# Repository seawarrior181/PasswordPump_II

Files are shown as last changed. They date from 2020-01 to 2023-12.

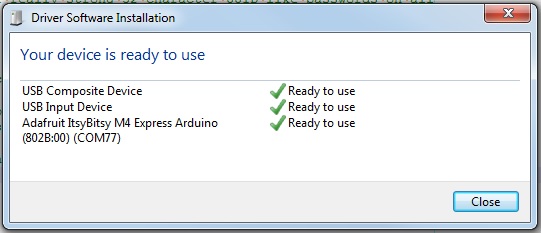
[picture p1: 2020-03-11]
media/DeviceDriversInstalled.jpg

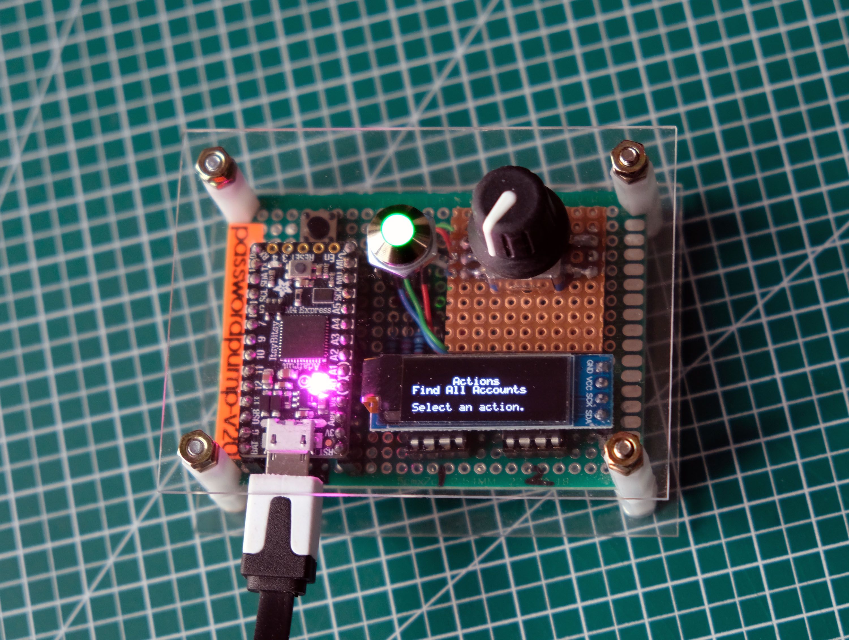
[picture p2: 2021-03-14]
media/NewDesignByCustomer.jpeg

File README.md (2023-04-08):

# PasswordPump v2.0

This is v2.0 of the PasswordPump, a USB device that manages credentials for up to 250 accounts.  Credentials (account names, usernames, passwords, URLs and old passwords) are stored ONLY on the device itself, on two removable EEprom chips using military grade encryption (AES-256).  The credentials are not stored in the cloud or in a file on your computer where they are more exposed to hackers.  Credentials are backed up on the device itself; i.e. encrypted credentials are moved from the primary EEprom chip to the backup EEprom on demand.  You may remove the EEprom chips from the device (perhaps to keep a third or fourth backup).  Credentials are entered either via the rotary encoder (on the left), via keyboard and serial terminal, or via a Python based graphical user interface (the PasswordPumpGUI).   The device itself is approximately 1 1/8 x 2 3/4 inches, or 29 x 71 millimeters.  Cases are available for printing.  If you design another case for the PasswordPump please share it with us!

The purpose of this repository on GitHub is to disseminate software for and information about the PasswordPump v2.0.  See the Password Pump II Users Guide.pdf and https://5volts.org for details.  

If you are simply wanting to download the latest version of the PasswordPump software onto your PasswordPump device follow the instructions provided in the "Burning Firmware From the BOSSA GUI" section of the Users Guide.

It is always wise to download the latest version of the PasswordPumpGUI when you are downloading the latest version of PasswordPump_v_2_0.ino.

If you are interested in printing the case (at https://github.com/seawarrior181/PasswordPump_II/blob/master/3D-Print), take a look here https://github.com/seawarrior181/PasswordPump_II/tree/master/media for pictures and instructions related to how the case can be further modified.  Thanks to Kevin Lever for these suggestions.

Note about v2.0.5 of the PasswordPump:
If I shipped to you a PasswordPump which indicates that it is at v2.0.5, it will most likely have a "lefty" encoder.  This means that as you turn the rotary encoder clockwise, it proceeds backwards through the alphabet instead of forwards.  Some folks find this counter intuitive.  To fix this you merely need to navigate to Settings->Encoder Type and change it from ‘Normal’ to ‘Lefty’; and don’t worry, the setting is remembered if you power cycle the device.  If you factory reset the device you’ll need to change the Encoder Type to Lefty again.

# News
  * The .stl files for the Joystick Model case have been posted, thanks to Scootercommuter.
  * A new release of the firmware is available, Version:2.0.8.02, which addresses an issue with the handling of group names between the PasswordPump and the PasswordPumpGUI.
  * There is now a new model of PasswordPump available for purchase; the Joystick model.  This PasswordPump has a lower profile, but it does take a little bit longer to scroll through all of your accounts.  It works well.
  * On Windows there exists now a setup program that does not require Python to be installed to get the PasswordPumpGUI up and running.  Click on it's location to download:
      https://github.com/seawarrior181/PasswordPump_II/raw/master/v2_0_8/PassPumpGUI/inno/PasswordPumpSetup.exe
    
    Simply execute the downloaded file to get the PasswordPumpGUI installed.
      
  * There are several new cases to announce; there is a new case for the rotary encoder model available on Tindie.  Soon to follow there will be a new case available for the Joystick model that looks pretty cool.  Both of these cases were designed and donated by scootercommuter.  Because 3D printing is expensive I'll be selling them on Tindie for a price that's quite close to my cost.  Finally there is an acrylic enclosure on the way, the enclosure that's depicted on the front of the Users Guide.  The .stl files for the two cases are posted on this site so that you can print them out yourself if you have a 3D printer (thanks scootercommuter!).  Finally, if you are interested in any of these cases/enclosures and they are not in stock on Tindie send me an email so that I know there is interest.  There are pictures of all three designs in the media section of this site, located here (best viewed by downloading):

      https://github.com/seawarrior181/PasswordPump_II/blob/master/media/PPEncoder.jpg
      https://github.com/seawarrior181/PasswordPump_II/blob/master/media/PPEncoderEnclosure.jpg
      https://github.com/seawarrior181/PasswordPump_II/blob/master/media/PPEncoderCase.jpg
      https://github.com/seawarrior181/PasswordPump_II/blob/master/media/PPJoystick.jpg
      https://github.com/seawarrior181/PasswordPump_II/blob/master/media/PPJoystickCase.jpg
  
# Change Log

v2.0.8 2023-04-08
  * Added a feature whereby if your Settings-->Timeout Minutes is set to Never, your screen goes dark after 5 minutes of inactivity.  Then you may actuate the rotary encoder in any way (which is automatically interpreted as a long click) to turn the display back on.  The purpose of this feature is to prevent the screen from burning in, a problem I've noticed after long-term use of the PasswordPump.

v2.0.8
  * When you backup to PasswordPump format from PasswordPumpGUI any custom group/category names are now saved.
  * A defect that was preventing the import of Chrome formatted export files is addressed.
  * Fixed an issue with the handling of group names between the PasswordPump and the PasswordPumpGUI.
  * Created an install/setup program for the PasswordPumpGUI using Inno.
  * Modified the PCB design to accomodate a joystick instead of a rotary encoder.
  * Added compile time directives to compile for rotaray encoder or joystick model.
  * Added the ability to download the latest version of the PasswordPumpGUI to the PasswordPumpGUI.
  * Added the ability to download the latest versions of the firmware from the PasswordPumpGUI.

2020-12-31 v2.0.6
  * Made some minor edits to the PasswordPumpGUI menus
  * Accepted design docs for an exceptionally well done case, here: https://github.com/seawarrior181/PasswordPump_II/tree/master/3D-Print/scootercommuter_Design
  * Added a setting that allows for the introduction of delay between the transmission of each character to the compuer/tablet/phone so that slower devices do not drop characters. 
  * Added the ability to set the default length of the generated password; 8, 10, 16, 24, or 31.
  * Fixed a problem with saving PasswordPump export files on Linux.
  * Added encryption and decryption of PasswordPump export files produced in PasswordPumpGUI.
  * Added a dialog box used on exit to confirm exit from PasswordPumpGUI.
  * Fixed an issue with style default value sometimes not getting handled correctly in PasswordPumpGUI.
  * Enforced a rule that device generated passwords must pass the same compexity check as the PasswordPumpGUI generated passwords.
  * Added the ability to edit RGB LED intensity, login attempts before logout, and  minutes before automatic logout from the PasswordPumpGUI.
  * Changed the behavior of sending a password so that a <TAB> character is sent before the <CR> carriage return character is sent.  This helps with automatically logging all the way into certain sites.
  * Added a feature whereby after 1 minute of inactivity the time remaining before automatic logout is displayed on the device.
  * Fixed a defect in PasswordPumpGUI whereby you could navigate to and edit fields before the port was open, resulting in the display of error messages.
  * Cleaned up Factory Reset to reset more values, like keyboard language, encoder type, logout timeout, so that they would not persist after a soft reset (a reset performed by selecting Factory Reset from the menu).  The values were not persisting after a hard reset.
  * Fixed a defect in Fix Corruption whereby if the head of the linked list was deleted, Fix Corruption would effectivly wipe out the ability to navigate to all accounts.
  * Updated the version number from v2.0.5 to v2.0.6.

2020-10-17 v2.0.5

  * Added the fix corrupt account list feature to the PasswordPumpGUI_v2_0.py.
  * A customer has recently reported to me that the linked list that keeps the credentials sorted by account name is becoming corrupt, which is affecting his ability to navigate through the credentials on the device via the rotary encoder or via the PasswordPumpGUI.  Toward fixing that problem I have added a menu option entitled Fix Corruption.  It is not clear to me yet how this corruption is introduced, as I am unable to reproduce the conditions under which the defect occurs in my lab.
  * Added a feature in settings whereby you can remap the orientation of the PasswordPump's text so that you can use it with the rotary encoder on the left (default) or the right.
  * Added the ability in settings to select from a variety of fonts for the PasswordPump's display.
  * Fixed several issues with menu navigation; selecting 'N' and not being returned to the top of the main menu, long clicking and the screen not clearing.
  * Removed the font fixednums8x16 which wasn't working, resulting in losing all creds.
  * Changed the default font.
  * Added a feature whereby the user can select from a variety of different fonts.

2020-07-24 v2.0.4 
  * Made the encoder type configurable; i.e. to handle 'lefty' encoders w/o the precompiler directive.
  * Fixed a problem with the way PasswordPumpGUI handled style when it's set to 255 (the default before it's written to EEprom).
  * Added support for Czech, Danish, Swedish, Norwegian, Finnish, French, German and Spanish keyboards.  US is the default.  See the Known Defects section of the Users Guide for more information about this functionality.
  * Fixed a problem with navigating back to the correct main menu elements on long click.
  * Fixed the Style dropdown in PasswordPumpGUI to show the inter username / password character's name instead of the value stored behind the scenes.
  * Added a check in PasswordPumpGUI for password complexity.  Informational only.
  * In the PasswordPumpGUI, added the ability to check to see if your password has ever been discovered in a known data breach (pwned).
  * Added the ability to customize the group names via PasswordPumpGUI.  
  * Added Factory Reset to the PassPumpGUI program. 
  * Added a pre-compiler directive to deal with "lefty" rotary encoders; see users guide for more info.  (Obsolete). 
  * Modified the custom PCB and added a pre-compiler directive for use with Adafruit ItsyBitsy M0. 
  * Fixed the defect whereby entering the decoy password did not result in a factory reset. 
  * Tweaked the mechanism for generating a random seed.  
  * Fixed the following defect: Via PasswordPumpGUI Insert, then (Alt)(Tab) to navigate to another application;  Upon returning to PasswordPumpGUI the Account Name is "Unknown";  Set focus to another account, the PasswordPump and PasswordPumpGUI freeze;  Close the PasswordPumpGUI window and long click on the PasswordPump;  Now there is only one account in the PasswordPump; Restore from secondary EEprom.  This issue is resolved.

2020-04-26 v2.0.3 
  * Fixed a defect discovered by Neil whereby the @ needed to be added back to the list of characters available for input via rotary encoder.  
  * Fixed an error whereby you could scroll past the z when entering characters via rotary encoder.  
  * Changed automatic logout from the device so that it does not automatically lock your computer. 
  * Fixed a defect whereby when long clicking after search by group you didn't return to the right group you always returned to favorites.  
  * Changed the Credentials menu so that you always know which account you're in.  
  * Fixed a problem in the Settings menu where you were not returning to the menu item from which you came.  
  * Fixed some issues with menu navigation when long clicking to make it more intuitive.  
  * Added the ability to customize the names of groups.  
  * Fixed a defect in PasswordPumpGUI whereby the value of a text box where the cursor is positioned before the Insert menu item is selected becomes blank after a new record is inserted by eliminating Insert (and Delete) from the File menu and substituting buttons for those functions. 
  * Fixed an issue discovered by Neil whereby the custom group names were not reflected in PasswordPumpGUI.

2020-02-24 v2.0.2 Eliminated the need for the PyCmdMessenger edits.  You still need to install PyCmdMessenger, you just don't need to make any edits to it.

2020-02-22 v2.0.1 Fixed an issue whereby the 124th account was not handled correctly under a variety of different situations.  Changed PassPumpGUI_v2_0_0.py and PasswordPump_v_2_0_0.ino.

2020-02-17 v2.0.0  Versioned all of the programs and documention, set them to v2.0.0.  There were minor cosmetic changes to the software related to the new version number.  PasswordPumpGUI was modified to size the main window based on the operating system.

2020-02-15 no rev  Added a feature whereby when you select logout from the main menu on the PasswordPump, you're logged out of the PasswordPump and the computer screen is also locked.  Changes the behavior of the splash screen; no more scrolling PasswordPump and a faster startup.

# Video

https://youtu.be/f4Iukt5VDUo

# License

<br />This work is licensed under a <a rel="license" href="http://creativecommons.org/licenses/by-nc-sa/3.0/">Creative Commons Attribution-NonCommercial-ShareAlike 3.0 Unported License</a>.

This program and device are distributed in the hope that they will be 
useful, but WITHOUT ANY WARRANTY; without even the implied warranty 
of MERCHANTABILITY or FITNESS FOR A PARTICULAR PURPOSE.

(c) 2020 Daniel Murphy

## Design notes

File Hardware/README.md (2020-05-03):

  
Note that the board in the DIPTrace PCB design is actually an ATMega32U4, not an ItsyBitsy M4, so the pad names are wrong.
This does not affect the design of the PCB.

I’m using DIPTrace to do the PCB design.  It’s freely available at https://diptrace.com/.  Download the DIPTrace file and open it with DIPTrace to edit the PCB design.  This is really the first PCB I’ve ever designed, so if you have suggestions please feel free to let me know.  I’ve also included the design files you’ll need if you want to order the custom PCB on your own.

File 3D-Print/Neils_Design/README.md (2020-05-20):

This case design is donated by my friend and beta tester Neil.  The design works best with this high quality magnetic USB cable: https://www.amazon.co.uk/NetDot-Generation-Magnetic-Smartphones-i-Product/dp/B07QKNF8Y7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

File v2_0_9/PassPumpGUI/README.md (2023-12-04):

# The PasswordPump Graphical User Interface

A project that exists to install the PasswordPumpGUI, [the Users Guide for which is found here][Users Guide].  Reading the users guide is stongly recommended before making a decision to acquire a PasswordPump.

[The source for this project is available here][src].

----

This is the README file for the project.

The PasswordPump is a USB device that manages credentials for up to 250 accounts.  Credentials (account names, usernames, passwords, URLs and old passwords) are stored ONLY on the device itself, on two removable EEprom chips using military grade encryption (AES-256).  The credentials are not stored in the cloud or in a file on your computer where they are more exposed to hackers.  Credentials are backed up on the device itself; i.e. encrypted credentials are moved from the primary EEprom chip to the backup EEprom on demand.  You may remove the EEprom chips from the device (perhaps to keep a third or fourth backup).  Credentials are entered either via the rotary encoder (on the left), via keyboard and serial terminal, or via a Python based graphical user interface (the PasswordPumpGUI).   The PasswordPump works with Windows, Mac OS, Linux distributions and Android (phones and tablets).  The device itself is approximately 1 1/8 x 2 3/4 inches, or 29 x 71 millimeters.

Features
- Stores up to 250 sets of credentials.
- Authenticates with a 15 character master password.
- Search for accounts.
- Data entry via rotary encoder or keyboard and serial monitor, or via client Python GUI running in Windows, Ubuntu, or MacOS.
- Sends a username and password to a computer as if typed in via the keyboard. Can also send URL, old password and account name.
- Add account name, username, password (generated or not), URL, old password
- Accounts are added in alphabetical order.
- Delete an account.
- Edit existing username, password, URL, style (inter-username/password characters, username<Return>password<Return>, username<Tab>password<Return> or username<Tab>password<Tab><Return>), old password, credential groups.
- Generate 8, 10, 16, 24, or 31 character random passwords from the PasswordPump or via the client GUI.
- Automatically saves the old password if it’s not already populated when you generate a password.
- Backup all accounts to a second encrypted external EEprom.
- Logout / de-authenticate via the menu, automatically locks the computer (Windows only).
- Configurable password display on or off.
- Configurable failed login count factory reset (3, 5, 10 or 25).
- Configurable automatic logout after count of minutes (30, 60, 90, 120, 240, 1 or Never).
- Configurable RGB LED intensity (high, medium, low or off).
- Configurable font.
- Configurable orientation, so that the encoder is on the left or the right.
- Configurable generated password size; 8, 10, 16, 24, 31.
- All account names, usernames, passwords and URLs are encrypted w/ AES-256.
- Master password is hashed w/ SHA-256.
- All encrypted credentials fields and the hashed master password are salted.
- The device is not vulnerable to standard password attacks.  See disclaimers.
- The master password can be changed.
- Export to PasswordPump formatted CSV file.
- Import from PasswordPump formatted CSV file.
- Import credentials from Chrome export.
- Import credentials from KeePass export.
- Associate credentials with custom groups for better organization; search by group (defaults are Favorites, Work, Personal, Home, School, Financial, Mail or Health).
- Decoy password feature that automatically factory resets the device if entered (e.g. while the user is under duress).
- Pre-auto-logout indicator/countdown via red and blue flashing RGB LED.
- Factory reset via menu (when authenticated) wipes out all credentials.
- Check if any password has been recovered in a data breach (pwned) on demand.
- Preliminary support for Czech, Danish, Swedish, Norwegian, Finnish, French, German, Spanish, United Kingdom and United States keyboards.
- Displays time left until automatic logout from the device occurs.
- Allows for setting Inter Character Delay for compatibility with some phones and tablets.

[Users Guide]: https://github.com/seawarrior181/PasswordPump_II/blob/master/Password%20Pump%20II%20Users%20Guide.pdf
[src]: https://github.com/seawarrior181/PasswordPump_II

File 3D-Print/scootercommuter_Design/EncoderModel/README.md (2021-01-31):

Here's are some cases made by scootercommuter in OpenSCAD.  All dimensions are calculated in OpenSCAD from the assembled board dimensions (by his caliper measurements). 

With respect to the Rotary Encoder case:
* The cover can be put on, and removed, without removing the knob (easier on the rotary encoder).
* It has rounded corners, which I personally prefer.
* The USB cable hole is made to fit the USB cable supplied by the PasswordPump Store.  The top is slotted for the cable also.  Probably most cables will fit.
* The fit of the knob hole is dependent on the positioning of the rotary encoder when it is soldered in.  So, he left a lot of slack with the hole size.
* Only 3 screws can be used due to the positioning of the RGB LED.
* It needs to be printed with supports enabled, because of the countersink holes and the oval USB hole.

It is designed for M2 x 8mm screws and hex nuts.  He had button hex head screws, but pan head will work just fine.  Scootercommuter had an issue with the "Hilitchi" brand screws he bought -- the "8mm" long screws are actually just 7.85mm long, so they barely were able to engage the hex nuts.  During his struggles with this, he opted for hexagonal countersink holes for obvious reasons.

The Joystic case is very similar to the encoder case, except it is designed to work well with the Joystick model of the PasswordPump.  It also has nubs that fit over the joystick for a professional finish.  

Print out a case on your 3D printer or order one from ThingVerse.  They cost about $12 to print in quantity (an order of 10 or more).

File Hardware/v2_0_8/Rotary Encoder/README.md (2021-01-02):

This version of the PasswordPump custom PCB (v2.0.7) will accomodate the Adafruit ItsyBitsy M0 or the Adafruit ItsyBitsy M4; with the RGB LED working correctly with either board.

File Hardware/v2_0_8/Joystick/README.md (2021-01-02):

This version of the PasswordPump custom PCB (v2.0.8) will accomodate the Adafruit ItsyBitsy M0 or the Adafruit ItsyBitsy M4; with the RGB LED working correctly with either board.

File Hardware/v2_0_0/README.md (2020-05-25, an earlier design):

This is the directory for v2_0_0 of the PasswordPump custom PCB.  It will accomodate the Adafruit ItsyBitsy M4 or the Adafruit ItsyBitsy M0; however, with the M0 the RGB LED will not always work correctly.

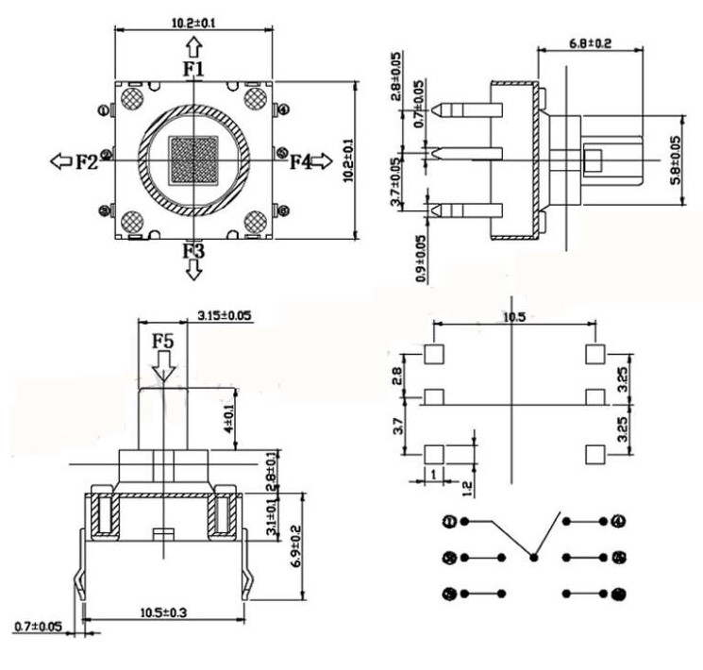
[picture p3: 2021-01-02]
media/JoystickPinout.jpg

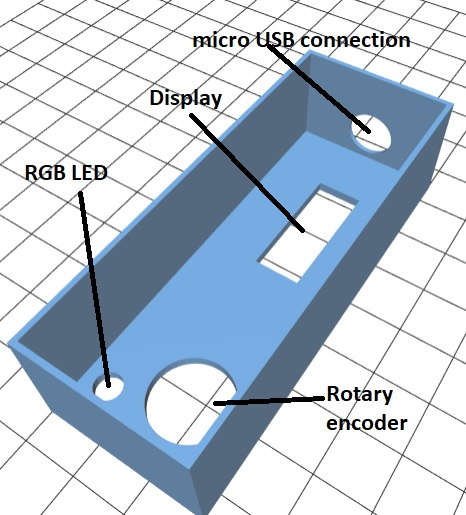
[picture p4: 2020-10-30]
media/CaseDesignInfoTop.jpg

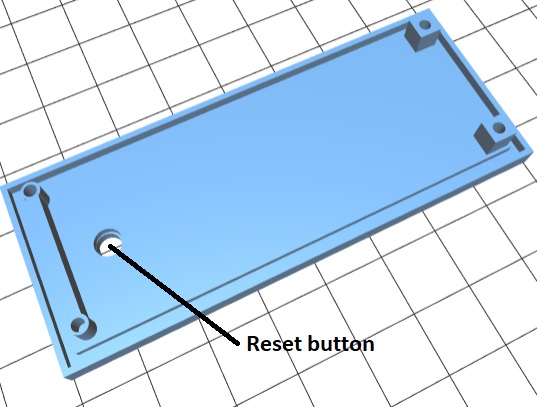
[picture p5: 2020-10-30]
media/CaseDesignInfoBottom.jpg

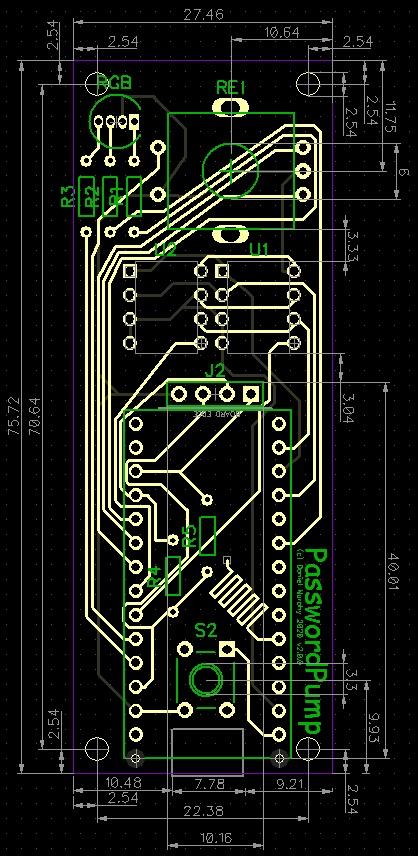
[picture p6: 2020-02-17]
Hardware/PasswordPumpDimensions.jpg

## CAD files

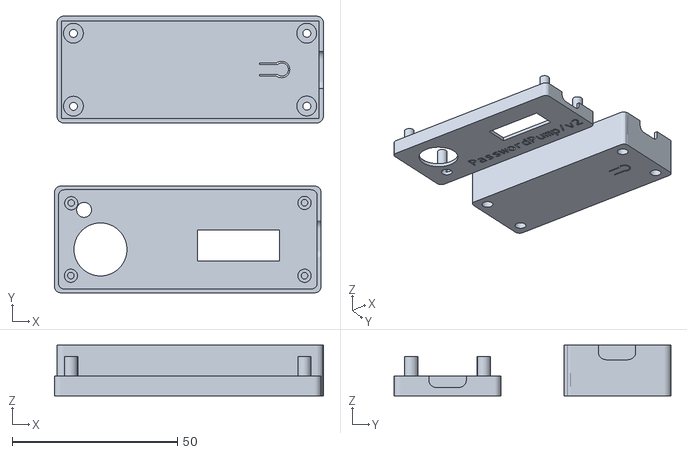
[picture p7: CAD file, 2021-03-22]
3D-Print/Jimmys_Design/PassPumpCase.stl
81.3 x 83.6 x 15.3

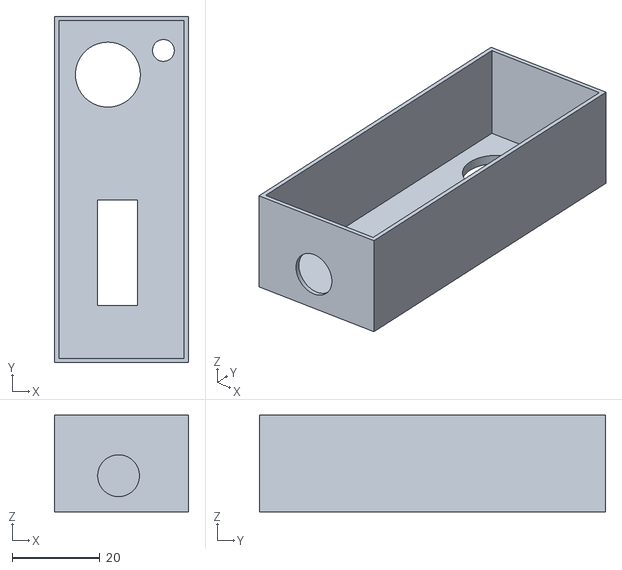
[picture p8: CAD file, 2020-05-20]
3D-Print/Neils_Design/passpump-v2-top.stl
30.5 x 78.7 x 21.9

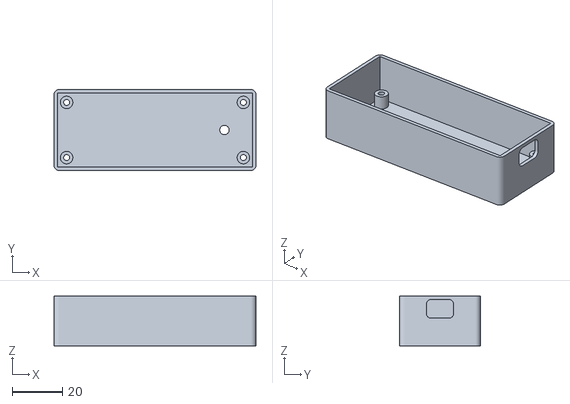
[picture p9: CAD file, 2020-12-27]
3D-Print/scootercommuter_Design/EncoderModel/EncoderPwdPumpBoxV2-kl6.stl
80.5 x 32.2 x 19.8

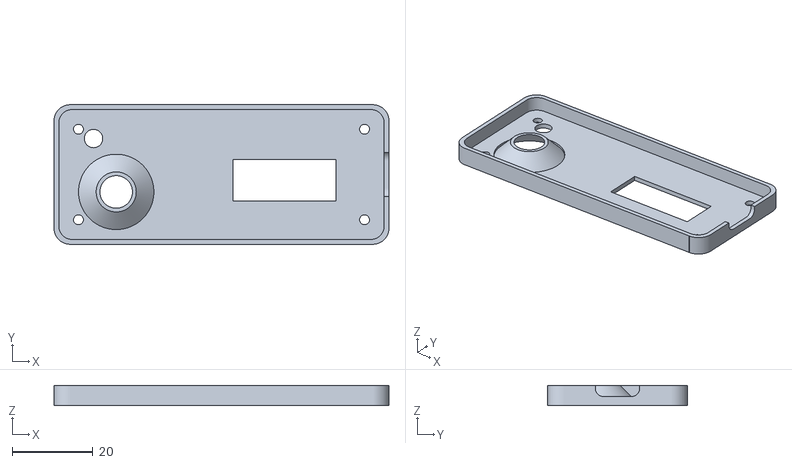
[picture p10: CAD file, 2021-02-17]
3D-Print/scootercommuter_Design/JoystickModel/PwdPumpV2_Joystick-Lid.stl
82.7 x 34.5 x 5.00

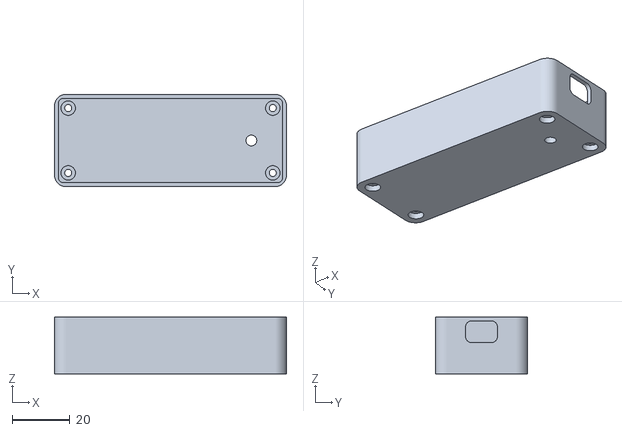
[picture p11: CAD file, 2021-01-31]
3D-Print/scootercommuter_Design/JoystickPwdPumpV2-Box.stl
80.1 x 31.9 x 19.6

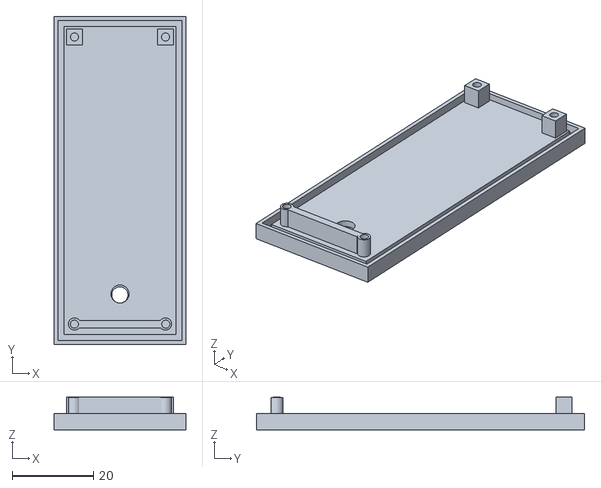
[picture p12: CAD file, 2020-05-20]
3D-Print/Neils_Design/passpump-v2-bottom.stl
32.5 x 80.7 x 8.00

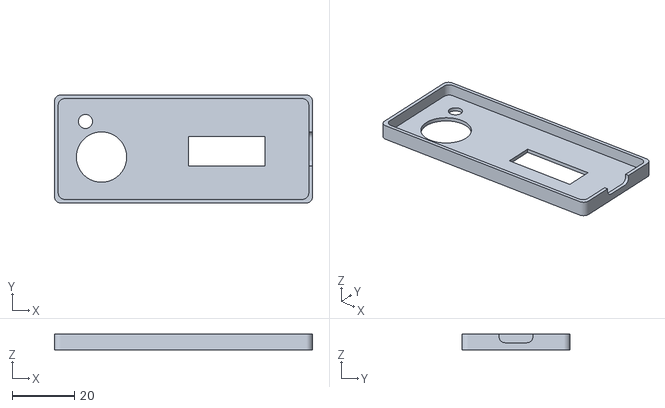
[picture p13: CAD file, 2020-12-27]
3D-Print/scootercommuter_Design/EncoderModel/EncoderPwdPumpLidV2-kl6.stl
83.2 x 34.9 x 5.00

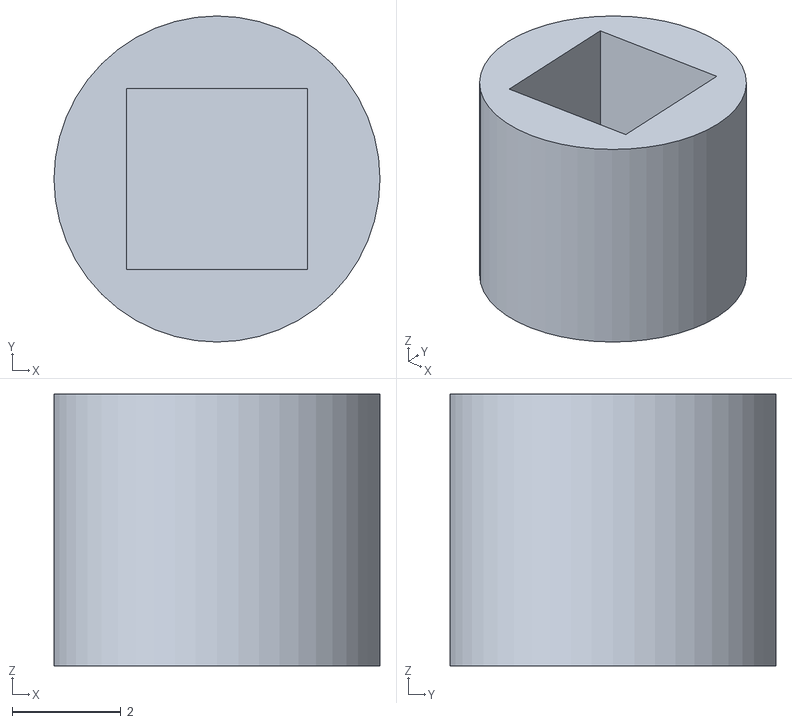
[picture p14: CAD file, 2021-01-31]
3D-Print/scootercommuter_Design/JoystickNubSqr2p2.stl
6.00 x 6.00 x 5.00

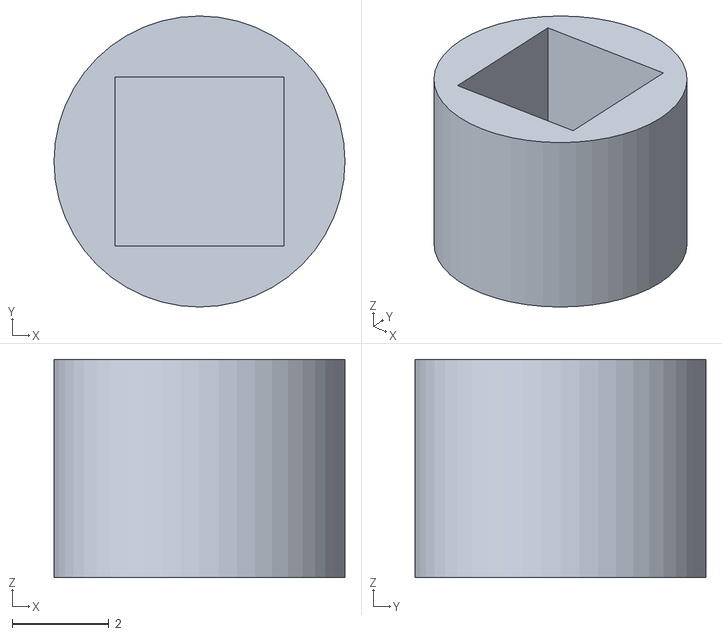
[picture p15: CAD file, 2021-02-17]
3D-Print/scootercommuter_Design/JoystickModel/JoystickNubSqrL3-Short.stl
6.00 x 6.00 x 4.50

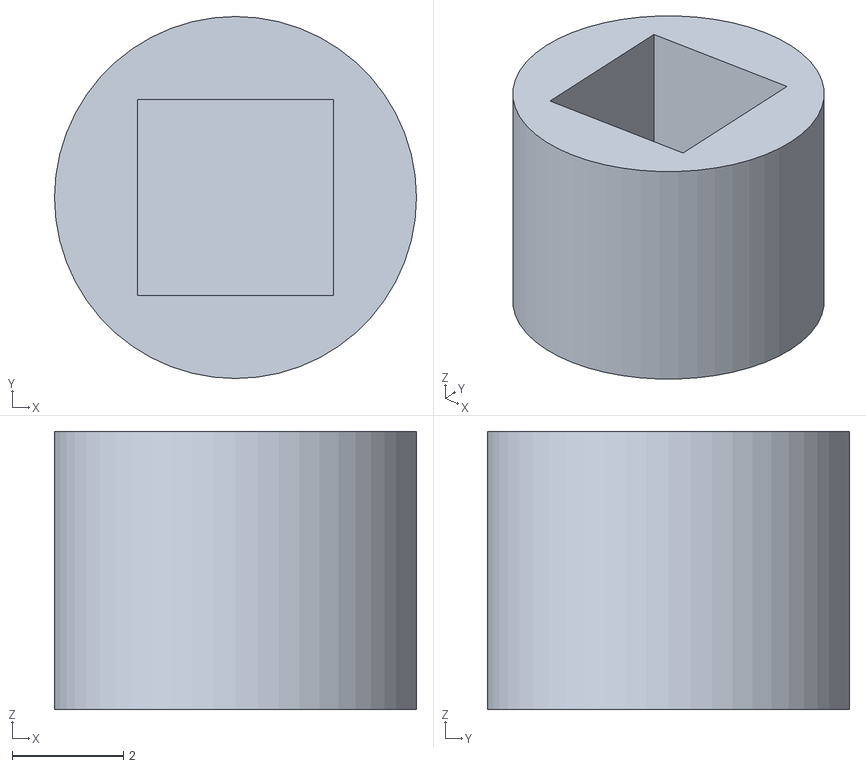
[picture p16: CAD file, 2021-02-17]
3D-Print/scootercommuter_Design/JoystickModel/JoystickNubSqrL4-Short.stl
6.50 x 6.50 x 5.00

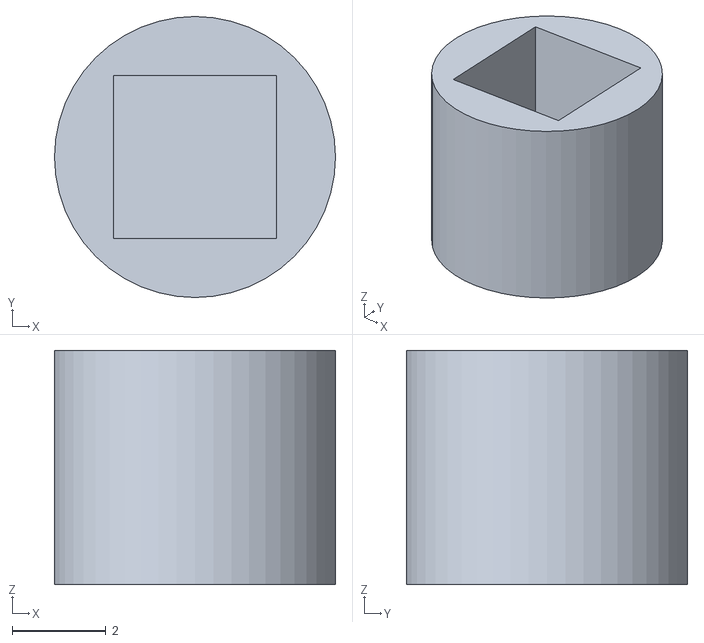
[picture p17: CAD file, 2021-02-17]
3D-Print/scootercommuter_Design/JoystickModel/JoystickNubSqrL3.stl
6.00 x 6.00 x 5.00

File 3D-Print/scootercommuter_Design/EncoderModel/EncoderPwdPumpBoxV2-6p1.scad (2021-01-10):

//	PasswordPumpV2Box v6
//
//		By: scootercommuter
//
//		License: Creative Commons, Attribution
//
//		Updates for v6.1
//			In this version, do not modify object geometry.
//			Do comment and code cleanup.
//		Changes in v6.0
//			Parameterize mount holes, countersinks and standoffs

use <MCAD/boxes.scad>
$fa=1;
$fs=0.4;

create_box = false; 
create_lid = true;

part_separation = 5;	//	if generating both parts in one STL, 
								//	separate them by this y distance

//		=  =  =  =  =  =  =  =  =  =  =  =
//		Dimensions for the Lid and Holes
//		=  =  =  =  =  =  =  =  =  =  =  =

lid_h			= 5;			// total lid height
ltop_h		= 1.2;		// height (thickness) of top of lid
lid_wall	= 1.2;		// thickness of the lid wall
lid_slack	= 0.2;		// how tight the lid fits

//		LCD window
lcdw_l = 24.6;
lcdw_w = 9.5;
lcd_l_offset =  1.6;		// center of board (x) to right edge of lcd window
lcd_w_offset = -5.5;		// center of board (y) to lower edge of lcd window

//		Knob hole
kh_d = 16.2;
kh_l_offset = -26.425;	// center of board (x) to center of knob hole
kh_w_offset = -2.6;		// center of board (y) to center of knob hole

//		LED hole
ledh_d = 4.55;
ledh_l_offset = -31.6;
ledh_w_offset =  8.875;

//		=  =  =  =  =  =  =  =
//		Dimensions for the Box
//		=  =  =  =  =  =  =  =

wall_w   = 1.4; // thickness of box case walls
c_radius = 2; 	// corner curve radius

//		circuit board dimensions
//
board_l       = 75.75;
board_w       = 27.45;
board_h       = 1.5;	 // thickness of circuit board
board_holes_l = 70.5; // center distance between board mounting holes
board_holes_w = 22;
board_slack   = 1.0;	 // edge of board to inside wall of box (per side)
top_slack     = 0.8;	 // top of screen to inside top of box
screen_offset = 10;	 // top of circuit board to top of screen

reset_button_offset_r = 10.2;		// right edge of board to center of reset button
reset_button_hole_dia = 3.75;

usb_cutout_offset = 5.75; // offset, horiz center of USB cutout above top of board
cable_housing_l = 9.95;   // supplied USB cable housing size
cable_housing_w = 6.50; 
housing_slack   = 1.0;    // clearance from edge of cable housing to hole edge

standoff_h = 5;
standoff_d = 5;			// max possible diameter to avoid running into board parts
standoff_hole = 2.4;	// drill for M2 screws

countersink_d = 5;			// countersink diameter for M2 hex nut
countersink_h = 2.2;		// countersink height for M2 hex nut thickness;
									// Actual s/b 1.6, increased since 8mm screws are too short.

bottom_h = 2.5; // thickness of bottom, must be greater than countersink height

//  =  =  =  =  =  =  =  =  =
//  =  End of Definitions   =
//  =  =  =  =  =  =  =  =  =

box_l = board_l + (wall_w * 2) + (board_slack * 2);
box_w = board_w + (wall_w * 2) + (board_slack * 2);
box_h = bottom_h + standoff_h + board_h + screen_offset + top_slack;

lid_l = box_l + (lid_wall * 2) + lid_slack;
lid_w = box_w + (lid_wall * 2) + lid_slack;

if (create_box == true) make_box();
if (create_lid == true) make_lid();

module make_box() {
	difference () {
		// Outside of box
		roundedBox(size=[box_l, box_w, box_h], radius = c_radius, sidesonly=true);
		// cutout inner box to create hollow box
		//		(inner box cutout has square corners to fit the circuit board corners)
		translate([0, 0, bottom_h])
			cube(size = [box_l - (wall_w * 2), 
									   box_w - (wall_w * 2),
									   box_h],center=true);
		// cut counter-sink holes for hex nuts, and round holes for screws
		mount_hole( board_holes_l/2,  board_holes_w/2, -box_h/2 );
		mount_hole( board_holes_l/2, -board_holes_w/2, -box_h/2 );
		mount_hole(-board_holes_l/2,  board_holes_w/2, -box_h/2 );
		mount_hole(-board_holes_l/2, -board_holes_w/2, -box_h/2 );

		// cut reset button hole
		translate([board_l / 2 - reset_button_offset_r, 0, -box_h / 2 - .001])
			cylinder(h = bottom_h + .002, r = reset_button_hole_dia/2);
		// cut USB cable hole
		translate([ (box_l - 2*wall_w)/2, 0,
							(-box_h / 2) + bottom_h + standoff_h + board_h + usb_cutout_offset ])
			rotate([90, 0, 90])
			roundedBox(size=[cable_housing_l + housing_slack,
									 cable_housing_w + housing_slack,
									 wall_w*2 + .002],
						   radius = c_radius, sidesonly=true);
	} // end difference()
	
	//	generate standoffs
	make_standoff( board_holes_l/2,  board_holes_w/2, -box_h/2 + countersink_h );
	make_standoff( board_holes_l/2, -board_holes_w/2, -box_h/2 + countersink_h );
	make_standoff(-board_holes_l/2,  board_holes_w/2, -box_h/2 + countersink_h );
	make_standoff(-board_holes_l/2, -board_holes_w/2, -box_h/2 + countersink_h );

}	// end module make_box

module mount_hole(x, y, z) {
	// countersink hex nut hole and cut through-hole for M2 screw
	translate([x, y, z - .001])
		cylinder(h=countersink_h + .001, r=countersink_d/2, $fn=6);
	translate([x, y, z - .001])
		cylinder(h=bottom_h + countersink_h + .002, r=standoff_hole/2);
} // end module mount_holes

module make_standoff(x, y, z) {
	difference() {
		translate([x, y, z])	// puts us at the top of the contersink cutout
			cylinder(h=standoff_h + bottom_h - countersink_h, r=standoff_d/2);
		translate([x, y, z - .001])
			cylinder(h=standoff_h + bottom_h - countersink_h + .002, r=standoff_hole/2);
	}
} // end module make_standoff

module make_lid() {
	// if we're generating both box AND lid, offset the lid by part_separation (y),
	//	set z origin to same origin as the box part, so they sit on the same base plane.
	y_move = create_box==true ? -box_w - part_separation : 0;
	z_move = create_box==true ? -box_h/2 + lid_h/2 : 0;

	translate([0, y_move, z_move])
		difference() {
			// Outside of lid
			roundedBox( size=[lid_l, lid_w, lid_h], radius = c_radius, sidesonly=true );
			// inside lid box cutout
			translate([0, 0, ltop_h])
				roundedBox(size=[ lid_l - 2*lid_wall,
										  lid_w - 2*lid_wall, lid_h],
					radius = c_radius, sidesonly=true);
			// lcd window cutout
			translate([ lcd_l_offset, lcd_w_offset, -lid_h/2 - .001 ])
				cube([lcdw_l, lcdw_w, ltop_h + .002]);
			// knob hole
			translate([ kh_l_offset, kh_w_offset, -lid_h/2 - .001 ])
				cylinder(h=ltop_h + .002, r=kh_d/2);
			// led hole
			translate([ ledh_l_offset, ledh_w_offset, -lid_h/2 - .001 ])
				cylinder(h=ltop_h + .002, r=ledh_d/2);
			// USB cable cutout
			translate([ (lid_l/2 - lid_wall) - .001, 0,
							lid_h/2 + 1 ])
				rotate([90, 0, 90])
				roundedBox(size=[cable_housing_l + housing_slack,
										 cable_housing_w + housing_slack,
										 lid_wall*2 + .004],
							   radius = c_radius, sidesonly=true);
		}
}	// end module make_lid

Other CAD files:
3D-Print/scootercommuter_Design/JoystickModel/PwdPumpV2_Joystick-Box.stl
3D-Print/scootercommuter_Design/JoystickPwdPumpV2-Lid.stl
3D-Print/scootercommuter_Design/JoystickModel/JoystickNubSqrL4.stl

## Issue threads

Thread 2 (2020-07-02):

Keyboard-Layout wrong/not changeable?

DHA81, 2020-07-02:
I'm in Germany and using german keyboard-layout,
passwords etc. are saved ok,
but they're sent wrong, could this be changed somewhere?
Had a look into keyboard-part of arduino, but can't find a way.

seawarrior181, 2020-07-03:
Follow the instructions in the users manual to burn https://github.com/seawarrior181/PasswordPump_II/blob/master/v2_0_4/PasswordPumpGerman_v_2_0.ino.bin firmware to your ItsyBitsy M4.  Remember to download also the corresponding PasswordPumpGUI file: https://github.com/seawarrior181/PasswordPump_II/blob/master/v2_0_4/PassPumpGUI/PassPumpGUI_v2_0.py .  Kindly let me know if it works.

DHA81, 2020-07-03:
Tried the bin file first, didn't work (nothing on screen, LED stays off), will try via arduino too.

DHA81, 2020-07-03:
Works via arduino.
Y isn't changed to Z anymore, but now the @ is a q...

DHA81, 2020-07-03:
Seems to be wrong in the german library, is simply sent as q instead of sending with "alt gr" (could be right alt).

DHA81, 2020-07-03:
Oh, have read again, have forgotten to run the script...

seawarrior181, 2020-07-03:
Did you purchase this on Tindie or are you building it on your own?

DHA81, 2020-07-03:
No, that didn't work too, seems to be really wrong in the library...

DHA81, 2020-07-03:
Tindie ;-)

seawarrior181, 2020-07-03:
Are you fallenangel81@freenet.de?

DHA81, 2020-07-03:
That's right ;-)

seawarrior181, 2020-07-03:
Ok I will issue a refund to you on the Tindie site.  I did create another binary file (in the same place) that you might want to try to burn: PasswordPumpGerman2_v_2_0.ino.bin   if you're up for it let me know how it goes.  I don't have a German keyboard here or any German language skills so it is difficult to troubleshoot.

DHA81, 2020-07-04:
You don't have to refund it, I think we could find a way 😉 Will try the binary as soon as I can.

DHA81, 2020-07-04:
New bin file starts, but also has " instead of @, tried the experimental Keyboard_DE, seems to work right, but there will be some missing ">","<" etc.
Yet i don't know what the finishGermanLayout.py script does, but something isn't done right, but it's a starting point for a solution ;-)
I don't have a problem if some developed devices don't work 100% from start, as long as there is no hardware-problem everything could get better.
So we'll see how it could be done better, i don't worry yet about some missing characters, just have to leave them away at new passwords yet.

DHA81, 2020-07-04:
Oh, additional, works on a huawei p30 pro via otg too, so will be using it on every device.
Currently i mostly use ubuntu, some experience with python and arduino, so i think i'll have a look if i could find a way too to get all characters, not that fast, but i think i'll find a way.

seawarrior181, 2020-07-04:
Hi DHA81,

The first .bin file I posted was built with Keyboard_DE.cpp, but I guess that file has some problem.  I think I may have built it with the wrong board selected in the Arduino IDE, so I will build it again and re-post it.  I also fail to understand the purpose of finishGermanLayout.py.  I definitely think that the solution is to get ...\arduino\libraries\Keyboard-master\src\Keyboard.cpp set up correctly.  I have versions of that file for Czech, Danish, Swedish, Norwegian, Finnish, French, German, Spanish and the US.  I guess the German version still needs some work.  If you get it straightened out please send me the Keyboard.cpp (and possibly Keyboard.h) file that works for you so that we can share it with others.  I greatly appreciate your help & patience.  If you change your mind about the refund don't hesitate to contact me, I am happy to oblige.

Best,
Dan Murphy
dan-murphy@comcast.net
5volts.org

seawarrior181, 2020-07-05:
I've re-added PasswordPumpGerman1_v_2_0.ino.bin, which was build using Keyboard_DE.cpp and Keyboard_DE.h.  This one should burn without any problems.

DHA81, 2020-07-07:
Found a workaround for all problems, changed the version by besoberlin a little bit, so all ascii-characters should work.
Uploaded the changed Version to https://pastebin.com/xhUFnu6M
Workaround at 237-247 and 297-309, commented some ascii-Chars.
Main-Problem is that the key for <>| has the hid-code 0x64, but besoberlin used 0x40 (alt-gr on german keyboard) in the table, so it would be detected wrong.
Changed it so if char is ascii 60, 62 or 124 then it would be handled outside of the table.
I don't know if there is a better way, but works ;-)

DHA81, 2020-07-07:
Oh, and your changed version of the bin-file had also the known problems with wrong chars, but now we have the workaround ;-)
And learned a bit more about it too ;-)

DHA81, 2020-07-07:
So yet this workaround could work for other languages with same keyboard-layout, i think it should be switchable inside the firmware, because if someone travels it could be possible that he has to use a pc with different layout.

seawarrior181, 2020-07-07:
Exceptional!  Thank you VERY MUCH for addressing this issue, you've done all of us a service.  I agree it should be switchable inside of the firmware and I need to figure out how to do that, it is on my list.  I will update the library and all of the documentation to explain how to get things to work with a German keyboard.  Well done!

seawarrior181, 2020-07-08:
Users' Guide is updated to explain how to compile with Keyboard_DE.h and Keyboard_DE.cpp into the product, yielding  a solution to the original problem.

Closed 2020-07-08.

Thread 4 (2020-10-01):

Some v2_0_5 fonts do not display correctly

JSField, 2020-10-01:
I originally used v2_0_4 firmware and it was working good. I noticed that I didn't have some of the settings, like the Font in Settings, so I upgraded to 2_0_5, which also worked. I decided to try changing to a different font (for screen readability). The line spacing seemed to be off with some of the fonts I tried, but with one of the fonts (not sure which one), the screen went blank. If I reboot the device, the screen is black, until I click and turn the knob and then the numbers show. But once I enter the master password, it is basically dark again. Sometimes half a number shows. I flashed back to 2_0_4 and it is ok, but if I flash back to 2_0_5, screen is blank.

seawarrior181, 2020-10-01:
JSField,

Thank you for reporting this, and apologies for the trouble.  The 2.0.5 code isn't "released" yet.  I thought I had removed all of the problematic fonts, but it seems there is one remaining.  The line spacing is a little off with all of the fonts, there's no space between the lines; so I'm on the fence with respect to continuing to move in that direction.  The library I'm now using isn't allowing me to specify the space between the lines.  I recommend sticking with 2.0.4 for now.  I have fixed a couple of minor bugs in 2.0.5, I will try to back port those fixes to 2.0.4.

Best,
Dan Murphy
dan-murphy@comcast.net
5volts.org

JSField, 2020-10-01:
No worries Dan. I am just wondering why when I re-flash 2.0.5 back, it seems to keep the problematic font and the screen is basically black. 2.0.5 looked ok until I changed the font. Is the font info stored on the eeprom? I thought when I re-flashed it would revert to the default font.
Jeff

seawarrior181, 2020-10-01:
Hi Jeff,

Yes, the font that you've selected is stored in EEprom, so in a way you've (or, I've) bricked it out of 2.0.5.  If you really want to install 2.0.5:

1) Flash to 2.0.4
2) Via PasswordPumpGUI, File->Export->Export to PasswordPump
3) On the device, Factory Reset (this clears out EEprom)
4) Flash to 2.0.5
5) On the device, reestablish a master password
6) Via PasswordPumpGUI, File->Import->Import from PasswordPump
7) Delete the file you exported in step #2 and empty your trash, or otherwise encrypt the file.

If you identify the offending font please let me know which one it is, and let me know how you make out.

Best,
Dan

JSField, 2020-10-01:
Ok, the bad font is the 'Fixednums8x16' one. The only really usable fonts are any of the 5x7 fonts.

Thanks,
Jeff

seawarrior181, 2020-10-02:
Thanks Jeff.  I noticed that a while back and update the code and the comments, but neglected to update the binary.  I will try to do that this weekend.

Best,
Dan

seawarrior181, 2020-10-02:
I've updated the .bin files in the M0 and M4 subdirectories.

Best,
Dan

Closed 2020-10-02.

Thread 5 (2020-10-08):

Output from PasswordPump is changed from caps to lower and vice versa

JSField, 2020-10-08:
Not sure if this something that happens because of the way you send the keyboard input. If you have Caps lock on, all Caps letters are changed to lower case and all lower case are changed to Caps. This happens with anything sent from the device.

seawarrior181, 2020-10-09:
Hi Jeff, thanks for the information.  I will add that to the Users Guide.  That's just the way it's always worked and as far as I know I have no control over it.  It's annoying when you're trying to login and the caps lock is down, just like when you're trying to login without the PasswordPump.  AFAIK there is no way for me to detect if the caps lock is engaged, so there is no way for me to reverse the case of the input to the computer.

Best,

Dan Murphy
dan-murphy@comcast.net
5volts.org

seawarrior181, 2020-10-09:
The troubleshooting section of the Users Guide has been updated to reflect this problem.  Thanks Jeff.

Closed 2020-10-09.

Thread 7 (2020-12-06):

suggestions for assembly instructions

wjcarpenter, 2020-12-06:
Thanks for going to the trouble of making this device. I was thinking of making something similar when I discovered your device on Tindie.

I just assembled 2 PasswordPump II devices from kits. In general, I found the assembly instructions excellent, and assembly is pretty easy for anybody with any soldering experience. Following are some suggestions/feedback on the assembly process. Everybody has their own favorite ways of doing things, so no offense taken if you choose to ignore these.

1. I wouldn't even bother with this first suggestion, except that your assembly instructions seem to want to help less experienced people. All of the pin headers used get assembled in what most people think of as "the normal way". If someone is less experienced, they might accidentally insert them in one of the three less common possibilities. Spacing is kind of critical for this kit due to vertical stacking, so you might want to be explicit about how to insert the pin headers. [Clarifying ... The usual header pins have a short end and a long end with a plastic spacer separating them. (You can actually slide the spacer around, but let's ignore that for this discussion.) The "usual way" is to insert the short end of the header from the bottom of the board and solder it on the top side of the board. Other ways would be to insert the long end form the bottom, insert the long end from the top, insert the short end from the top. Once the pin headers are inserted, there is only one choice about which side of the board takes the solder. Those other orientations are unusual, but they can be used for some special situations. So, for beginners, it would be helpful to say something like "The pin headers get the short end inserted from the bottom of the board, and then they are soldered in place on the top side of the board." Or, maybe that's overburdening the explanation. :-)]

2. I would attach the rotary encoder and maybe even the RGB LED as the last soldered components. The stem from the rotary encoder sticks up quite a bit and makes working on the back side of the board a little unstable if you don't have a good helping hands holder of some kind. As far as I can tell, saving them for later would not be any kind of assembly problem.

3. It's no surprise to anybody to say that mounting the display board is a little fiddly. There is a surface mount IC on the back of the display that really, really wants to push the reset button on the Itsy Bitsy. It's hard to hold everything in the right position to solder the display board pins in place while avoiding that reset pin and also getting a cosmetically good position for the display board. I used a different technique to mount mine (after desoldering my first miserable attempt).

- It's easy to remove the cap/plunger from the Itsy Bitsy reset button. (In fact, I was surprised how easy it was.) Using fine-nosed pliers, lift off the metal cap that holds the black button. Under that are 1 or 2 circular layers. Remove those, too. You should be left with 3 contact pads exposed from the internals of the switch. There will also be some tiny pieces of structural plastic and, of course, the solder tabs for the switch; it's OK to leave all that in place. With the switch deconstructed like that, it's nearly impossible to accidentally reset the Itsy Bitsy that way. That doesn't matter since you put an alternate reset button on the back of the main PCB.

- I used the rubber band trick given in the instructions to hold the display board against the top of the micro USB connector on the Itsy Bitsy. In other words, I put the rubber band on the end of the display board instead of the center. On the other end of the display board, I used a scrap piece of thick wire as a temporary spacer. That made it easy to see that the display board was level and straight. The rubber band keeps things from shifting.

- After soldering the display board pins on the back side of the main PCB, I removed the scrap wire spacer from under the display board by simply pulling it out. The result was perfect, and it was an easy process for getting good results.

seawarrior181, 2020-12-07:
Mr. Carpenter,

Thanks for taking the time to write up all of that feedback.  I will work it in the next time I'm taking pictures of the assembly process.  We have independently come to the same conclusions with respect to a couple of these suggestions, especially with respect to the order of assembly and the technique for attaching the display.

Best,

Dan Murphy

FleshdeckTV, 2020-12-07:
Hello, In terms of functionality, there is not enough setting for the length of the generated password, in some cases the password length of 31 characters is too long, can you add such functionality? Аnd I also saw that the firmware mentions different memory chips, 256, 512, 1024, but 512 is used, is it possible to use chips other than 512?

seawarrior181, 2020-12-07:
Yes it is possible to add a feature to the PasswordPump device whereby the length of the generated password can be specified as a setting.  I will take this suggestion into consideration.  You can also generate passwords in the PasswordPumpGUI, where it also generates a 31 character password, but of course you can easily make it any size you like with the backspace key.

It is not possible to substitute a chip other than the 25LC512 EEprom.  Too allow for such functionality in the program is possible, however I don't think it's a high priority because the 25LC512 provides for enough room to store 250 sets of credentials, which is more than enough for most people.

Best,
Dan

seawarrior181, 2020-12-08:
FleshDeckTV,

Today I enhanced the PasswordPump device by adding to it the ability to specify the default generated password size; 10, 16, 24 or 31.  The code is posted in v2_0_6.

Best,
Dan

seawarrior181, 2020-12-08:
RE: Mr. Carpenter, on suggestion #1; now understood, thank you very much for the clarification.

Dan

Closed 2020-12-08.

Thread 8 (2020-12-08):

feature suggestion: TOTP MFA

wjcarpenter, 2020-12-08:
This is a suggestion for a future feature.

What if PP could supply the 6-digit one-time codes that are used for multi-factor authentication? I got this idea from the Bitwarden password manager; after filling in credentials for an MFA-enabled account, it automatically copies the current 6-digit code to the clipboard for easy pasting. With PP, instead of copying to the clipboard, it would just be another field that could be supplied like username and password, with some kind of style for tabs, CRs, etc.

You probably already know that those 6-digit codes are a particular implementation of a standard called TOTP (time-based one-time passwords). People usually think of this as "the Google authenticator app", but there are many others that work with the same algorithm. Code to implement TOTP is not very difficult, and there are plenty of open source sample implementations around.

As the name implies, the tokens are time-based, which means the codes are created by a straightforward calculation based on a shared secret and the current timestamp. As mostly a simple keyboard emulator, PP doesn't care what time it is, but I believe the chip on the Itsy Bitsy does contain a real-time clock. Perhaps the PP GUI application could be enhanced to tell the PP device what the current time is. Obviously, the RTC would lose the time awareness when power is removed, but it would still be useful for those who leave the PP device plugged into USB most of the time. (A future hardware revision of the PP might have a coin cell battery to power the RTC, but the feature doesn't require it.)

Another difficulty with TOTP is that it requires a site-specific seed value called the authenticator key (a shared secret). The seed is encoded into those QR codes that can be scanned by a smart phone, but there is also a plain-text version of what is encoded in the QR code. Most apps that deal with TOTP will let you either scan the QR code or enter the plain-text seed manually (but once they have it, they are not interested in giving it back to you, which is annoying). The PP GUI could allow for entry of that plain-text seed. It could also be entered via the rotary encoder, but the text form of the seed is pretty long.

There's a theoretical argument that you would be defeating the benefit of MFA by doing having this feature since it would be storing the permanent password and the seed for the TOTP in the same device. The typical definition of MFA is "something you know and something you have". If you are using randomly generated passwords with a hardware or software password manager, which you should, then you already don't know the password. You are, in a sense, delegating things so that the "something you know" is the master password for the password manager. So, you haven't lost anything by also putting the TOTP in the password manager. (And, hey, if you're worried about it, just use two different PasswordPumps :-)).

wjcarpenter, 2020-12-08:
The TOTP algorithm is documented in https://tools.ietf.org/html/rfc6238. It includes a reference implementation in Java. This wikipedia article gives a short overview: https://en.wikipedia.org/wiki/Google_Authenticator. Once you know the right jargon terms to search for, you can find other open source implementations. The code for Google's implementation is here: https://github.com/google/google-authenticator

The spec includes a couple of options for variations. If anything is a bother to implement, you could get by with using the selections that the Google Authenticator app uses since that's what most web sites use.

seawarrior181, 2020-12-09:
Mr. Carpenter,

Thanks for the insightful suggestion.  I will keep this idea in mind for the future.  I really appreciate all the effort you invested in writing up this detailed suggestion.

Best,
Dan

Closed 2020-12-09.

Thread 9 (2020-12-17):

Option to slow down keypress signals, for use when inputting to a tablet

scootercommuter, 2020-12-17:
I suggest adding the ability to send keypress signals more slowly, as an on/off option.  We tried using the Password Pump with our Samsung tablet, using a USB-to-micro USB conversion cable.  The tablet was able to power the Password Pump and it will accept USB input, but it looked as if the input from the Password Pump was coming in too fast for the tablet to recognize all the characters -- it dropped quite a few.  I expect that if it were possible to slow down the sending of characters (Tablet, or Slow-Type mode?) we could use the Pump with the tablet.  Not a deal breaker for sure, we just won't use the tablet for any web sites where we're concerned about login security.

seawarrior181, 2020-12-17:
Thanks for the feedback.  I've noticed this too and it's on the list.

-Dan

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

seawarrior181, 2020-12-19:
Hi,

I'm working on this functionality this weekend and hope to release it to 2.0.6 soon.

Best,
Dan

seawarrior181, 2020-12-20:
Added a setting that allows for the introduction of delay between the transmission of each character to the computer/tablet/phone so that slower devices do not drop characters.  From the Settings menu select Inter Char Delay and select a delay of 0 (default), 10, 25, 100, or 250 milliseconds between the transmission of each character.  Available in the source and in the binary in the M0 folder (ItsyBitsy M0) under 2.0.6.  I'll place the M4 version of the binary in the morning.

wjcarpenter, 2020-12-21:
FWIW, I've also noticed some bad password pushes on a intermittent basis. I wasn't clear on what was going on, but the issue in this thread makes sense. Indiana lot of work over remote connections, and it could be that they sometimes can't cope with rapid fire "typing".

I'm glad you've already implemented the delay thing.

scootercommuter, 2020-12-22:
I loaded the M0 version, and IT WORKS on our Samsung tablet!  I set the character delay to 100, which is a little slow for general use but acceptable (but faster than most people can type), and we're able to send our credentials on both the desktop and the tablet.  Thanks!

seawarrior181, 2020-12-22:
Remember to also download the latest version of PasswordPumpGUI.  -Dan

Closed 2020-12-20.

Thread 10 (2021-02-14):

Backup (Export to Password Pump) does not save customized group names

scootercommuter, 2021-02-14:
In the Password Pump Gui I did an Export to Password Pump file, with encryption.  On my spare password pump I did a Factory Reset, set the password, and did an Import from Password Pump (file).  The Import worked just fine.  However I had previously customized three of the Group Names, and the customized names had been reverted to the non-customized group names.  THEN, on the original Password Pump (from which I'd done the Export) the un-customized group names showed up!  SO, in the Password Pump GUI I updated the group names I had previously customized.  At this point one of two things will happen.  If you do a long-click on the Password Pump before you close the GUI, the new names are not saved.  If you close the GUI first, the changes are saved on the Password Pump itself _as long as you Reset the device_.  It could be that just restarting it would do the trick.  At this point I had to repeat the process on my backup Password Pump.  In case it matters: one of the PPs was a Rotary Encoder model and the one I used for the original backup was the Joystick model.  Both had been upgraded previously to version 2.0.8, and the GUI is version 2.0.8.

seawarrior181, 2021-02-14:
ScooterCommuter,

Some of this is expected behavior, albeit a shortcoming that should be addressed.  Presently, when you backup your PasswordPump to a PasswordPump Export File format (a practice that is highly encouraged, encrypted), the custom names of the groups/categories are NOT saved, therefore they must be re-entered when restoring a PasswordPump from a PasswordPump Export File.  This will be addressed in a future release.

There is nothing about creating a PasswordPump Export File that touches the custom group names, therefore I am baffled by the behavior you witnessed whereby the customized group names reverted back to the defaults after you created the export file.  I create a PasswordPump Export File a couple of times a week and I have never lost the custom group names, so this is very concerning.

I will now work with the PasswordPumpGUI to see if I can reproduce the balance of the bad behavior you saw.

Thanks,
Dan

seawarrior181, 2021-02-15:
The defect whereby group names are not correctly handled between the PasswordPump and the PasswordPumpGUI is addressed in firmware release 2.0.8.02, available for download in the usual locations.  Thanks for reporting this defect.  Work to export the customized group names to the PasswordPump format is up next.

Best,
Dan

Closed 2021-02-15.

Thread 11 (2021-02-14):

V2.0.8, Enabling Decoy Password on the Password Pump freezes the Pump

scootercommuter, 2021-02-14:
On the Password Pump itself, Actions:Settings, Decoy Password locks up the Password Pump.  Have to hit the Reset button to regain control.  Show Password, RGB LED, Timeout Minutes, Login Attempts all work, I didn't try the other settings.  Choosing Decoy Password in the GUI seems to work, but I haven't tested whether it actually erases stuff.

seawarrior181, 2021-02-14:
Hi ScooterCommuter,

Thank you for reporting this defect  to me.  Are you able to reproduce the behavior at will?  I am not able to reproduce this error on my side.  What I have noticed is that for three settings, Decoy Password, Keyboard (not Keyboard Language), and Show Password,  after the device has been factory reset and before the user has set any of these settings, when first entering the menu it doesn't indicate if the setting is On or Off; it defaults to blank.  If you select blank it stays blank, but it doesn't freeze.  And selecting On or Off doesn't freeze it either, at least on my end.  Would you be able to try to see if you can make the PasswordPump freeze on demand?  Frankly I'd prefer it if we could get it to freeze consistently because intermittent defects can be extremely difficult to isolate and fix.  Thanks again for the report.  Parenthetically, I am working on a new version of the firmware this morning which addresses another defect I noticed on the joystick model when changing orientation.  I'll get to your other report in a bit.

Best,
Dan

seawarrior181, 2021-02-14:
Ok I have the version information, no need to re-report that.

seawarrior181, 2021-02-15:
ScooterCommuter, when you say the freezeup is only applicable to the joystick model, do you mean that you're not able to reproduce the problem on the rotary encoder model but you are able to reproduce the issue on the joystick model?

Thanks,

Dan

scootercommuter, 2021-02-15:
Yes, correct.  Always happens with my Joystick M0 model.  Not reproducible on Joystick M4, not reproducible on Rotary Encoder M0.

seawarrior181, 2021-02-16:
ScooterCommuter,

There's no behavior surrounding the management of that setting (decoy password on/off) that 'cares' about the model or the MCU type, and I'm not able to reproduce the behavior on my  M0 joystick model.  My only suggestion would be to upgrade to the latest version of the firmware and try again.  Please let me know if that addresses the issue.  If the issue persists, please answer the following question:  When you go to Settings->Decoy Password, does it display On, Off, or blank?

Best,
Dan

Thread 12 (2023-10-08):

Problem with Eagle brd file

JSField, 2023-10-08:
When trying to load the .brd file in Fusion 360 it gives the following error: line 957, column 38: attribute 'pad' references undefined object 'VCC' in tag <contactref>

seawarrior181, 2023-10-16:
Hi JSField,
Thanks for making me aware of this problem.  I used DIPTrace to design the schematic for the PasswordPump.  You should be able to open the .dip files I've published using that tool.  I created the .brd files by exporting from DIPTrace, so I suspect a defect in DIPTrace is responsible for the error you're seeing.

Best of luck,
Dan Murphy

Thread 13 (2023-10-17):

Unable to locate 4K7 ohm PCBs

Zpmqwertyuiop, 2023-10-17:
I can't find the 4k7 ohm PCB in the folder with path "PasswordPump_II-master\Hardware\v2_0_8", all the PCBs in there don't have 4k7 ohm, did you put the wrong file? Where should I find the PCBs with 4k7 ohms?

seawarrior181, 2023-10-21:
The 4k7 ohm resistors are unnecessary and do not appear on the PCB files after v2_0_4.

Zpmqwertyuiop, 2023-10-21:
Okay,thank you for your amswer.

seawarrior181, 2023-10-23:
You're welcome!

Closed 2023-10-23.

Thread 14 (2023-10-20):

Issue with the newest CmdMessenger Library

JVR01, 2023-10-20:
This error was shown while building for M0 in the Arduino IDE.

Arduino-CmdMessenger-master\CmdMessenger.cpp:492:9: error: invalid conversion from 'char' to 'char*' [-fpermissive]

  492 |  return '\0';

I added this small change in the library and it worked, not so elegant fix but got my PasswordPump_II running :)

The Fixed function:

```
char* CmdMessenger::readStringArg()
{
	if (next()) {
		dumped = true;
		ArgOk = true;
		return current;
	}
	ArgOk = false;

	//MIO fix
	char my_char = '\0';
	//End fix

	return &my_char;//orig---->return '\0';
}
```

seawarrior181, 2023-10-21:
Thanks for reporting the problem you encountered when using a different version of CmdMessenger.  For folks who want to avoid this problem I supply the version of CmdMessenger that is used to compile the PasswordPump_II code here: https://github.com/seawarrior181/PasswordPump_II/tree/master/Libraries/PyCmdMessenger-master.zip.  When you deviate from the recommended library versions you should expect to encounter problems, especially for the less frequently used libraries.

JVR01, 2023-10-21:
Yes Sir you're right. I did not notice you added the library (the recommended one) in the project folder. I got the CmdMessenger  library from the Link found in the .ino code.

So, I suppose that was the last Version which caused the problem.

seawarrior181, 2023-10-23:
Indeed.  Feel free to share with us any other modifications you're making to the source code, I am always interested in understanding what others are doing with the PasswordPump.

JVR01, 2023-10-24:
Definetly will try to add an erase button so that one can erase a character when a mistake is made. I also would really like to make it work with the basic raspberry RP2040, that one ist only $4 against the $14 I paid for the M0.

By the way, I installed  again each library in another computer using the libraries you provided, still encounter the Error with the conversion from 'char' to 'char*:

CmdMessenger
492 | return '\0';"

word around: See my original post.
(Maybe some update in Adafruit lib for ItsyBity or Arduino caused this, Idk)

It is the second time I encounter this error with sdFat library (this was not provided by you but is required for some other lib)

Adafruit_SPIFlash.h:38:2: error: #error ENABLE_EXTENDED_TRANSFER_CLASS must be set to 1 in SdFat SdFatConfig.h
   38 | #error ENABLE_EXTENDED_TRANSFER_CLASS must be set to 1 in SdFat SdFatConfig.h
      |  ^~~~~

work arround: do not install the one from the Repo but this one (also oficial I think): "SdFat___Adafruit_Fork-2.2.1"

I am still fascinanted by this project of yours, thanks for making it Opensource :)

seawarrior181, 2023-10-25:
Sorry for your troubles JVR1.  Definitly annoying to encounter those compile time errors.  Getting it working on a RP2040 (I am seeing it at $5.00 including WiFi) is a great idea, I have to admit the same thought crossed my mind (because of the cost of the M0), but I didn't pursue it.  The ItsyBitsy M0 is still $11.95; I suppose you are factoring it the cost of shipping.  I tend to buy them in bulk so less of an issue for me.  The ItsyBitsy M0 is open source.  I started looking into what it would cost to have that manufactured (to cut out Adafruit), but I'm not really confident enough in that aspect of the project to commit to having a large batch of them manufactured.  Getting the cost of the PasswordPump down by using the RP2040 is an excellent idea; the ItsyBitsy M0 is the most expensive component (although the two EEprom chips are also quite expensive now, I think the cost approaches $5).

Adding a means by which to erase a character is also sorely needed.  It will be tough w/o adding an additional component to the board.  Perhaps an extra long click of the rotary encoder would work.  I use the python app for editing credentials anyhow, that's really the best way to do it.

Best of luck to you, keep me updated on your progress and let me know if you have any questions about the code.

Dan Murphy

JVR01, 2023-10-26:
Thanks for your comments Dan, I really appreciate it. just wanted to share I made it compile for the RP2040 but had to make some compromises. I think the keyboard-language-choose feature is gone (It may be integrated again later).

I haven't tested yet in the breadboard and this won't happen in the next two weeks (I'll be off and will go with the Idea in mind that it's going to work :D) I'll keep you updated afterwards if it actually does.

Greetings!

Btw. I did pay 4€ for each Eeprom and 14€ for the M0 + Delivery. That was the best deal I found. Adafruit it's not that cheap in Europe.

Closed 2023-10-23.

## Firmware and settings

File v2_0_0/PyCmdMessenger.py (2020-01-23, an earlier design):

### COMMAND FORMATS

__description__ = \
"""
PyCmdMessenger

Class for communication with an arduino using the CmdMessenger serial
communication library.  
"""
__author__ = "Michael J. Harms"
__date__ = "2016-05-20"

import serial
import re, warnings, multiprocessing, time, struct

class CmdMessenger:
    """
    Basic interface for interfacing over a serial connection to an arduino 
    using the CmdMessenger library.
    """
    
    def __init__(self,
                 board_instance,
                 commands,
                 field_separator="~",
                 command_separator="|",
                 escape_separator="\\",
                 warnings=True):
        """
        Input:
            board_instance:
                instance of ArduinoBoard initialized with correct serial 
                connection (points to correct serial with correct baud rate) and
                correct board parameters (float bytes, etc.)

            commands:
                a list or tuple of commands specified in the arduino .ino file
                *in the same order* they are listed there.  commands should be
                a list of lists, where the first element in the list specifies
                the command name and the second the formats for the arguments.
                (e.g. commands = [["who_are_you",""],["my_name_is","s"]])

            field_separator:
                character that separates fields within a message
                Default: ","

            command_separator:
                character that separates messages (commands) from each other
                Default: ";" 
       
            escape_separator:
                escape character to allow separators within messages.
                Default: "/"

            warnings:
                warnings for user
                Default: True
 
            The separators and escape_separator should match what's
            in the arduino code that initializes the CmdMessenger.  The default
            separator values match the default values as of CmdMessenger 4.0. 
        """

        self.board = board_instance
        if not self.board.connected:
            err = "Arduino not connected on {}\n".format(self.board.device)
            raise IOError(err)

        self.commands = commands[:]
        self.field_separator = field_separator
        self.command_separator = command_separator
        self.escape_separator = escape_separator
        self.give_warnings = warnings

        self._cmd_name_to_int = {}
        self._int_to_cmd_name = {}
        self._cmd_name_to_format = {}
        for i, c in enumerate(commands):
            self._cmd_name_to_int[c[0]] = i
            self._int_to_cmd_name[i] = c[0]
            self._cmd_name_to_format[c[0]] = c[1]
 
        self._byte_field_sep = self.field_separator.encode("ascii")
        self._byte_command_sep = self.command_separator.encode("ascii")
        self._byte_escape_sep = self.escape_separator.encode("ascii")
        self._escaped_characters = [self._byte_field_sep,
                                    self._byte_command_sep,
                                    self._byte_escape_sep,
                                    b'\0']

        self._null_escape_re = re.compile(b'\0')
        self._escape_re = re.compile("([{}{}{}\0])".format(self.field_separator,
                                                           self.command_separator,
                                                           self.escape_separator).encode('ascii'))

        self._send_methods = {"c":self._send_char,
                              "b":self._send_byte,
                              "i":self._send_int,
                              "I":self._send_unsigned_int,
                              "l":self._send_long,
                              "L":self._send_unsigned_long,
                              "f":self._send_float,
                              "d":self._send_double,
                              "s":self._send_string,
                              "?":self._send_bool,
                              "g":self._send_guess}

        self._recv_methods = {"c":self._recv_char,
                              "b":self._recv_byte,
                              "i":self._recv_int,
                              "I":self._recv_unsigned_int,
                              "l":self._recv_long,
                              "L":self._recv_unsigned_long,
                              "f":self._recv_float,
                              "d":self._recv_double,
                              "s":self._recv_string,
                              "?":self._recv_bool,
                              "g":self._recv_guess}

    def send(self,cmd,*args,arg_formats=None):
        """
        Send a command (which may or may not have associated arguments) to an 
        arduino using the CmdMessage protocol.  The command and any parameters
        should be passed as direct arguments to send.  

        arg_formats is an optional string that specifies the formats to use for
        each argument when passed to the arduino. If specified here,
        arg_formats supercedes formats specified on initialization.  
        """

        # Turn the command into an integer.
        try:
            command_as_int = self._cmd_name_to_int[cmd]
        except KeyError:
            err = "Command '{}' not recognized.\n".format(cmd)
            raise ValueError(err)

        # Figure out what formats to use for each argument.  
        arg_format_list = []
        if arg_formats != None:

            # The user specified formats
            arg_format_list = list(arg_formats)

        else:
            try:
                # See if class was initialized with a format for arguments to this
                # command
                arg_format_list = self._cmd_name_to_format[cmd]
            except KeyError:
                # if not, guess for all arguments
                arg_format_list = ["g" for i in range(len(args))]
  
        # Deal with "*" format  
        arg_format_list = self._treat_star_format(arg_format_list,args)

        if len(args) > 0:
            if len(arg_format_list) != len(args):
                err = "Number of argument formats must match the number of arguments."
                raise ValueError(err)

        # Go through each argument and create a bytes representation in the
        # proper format to send.  Escape appropriate characters. 
        fields = ["{}".format(command_as_int).encode("ascii")]
        for i, a in enumerate(args):
            fields.append(self._send_methods[arg_format_list[i]](a))
            fields[-1] = self._escape_re.sub(self._byte_escape_sep + r"\1".encode("ascii"),fields[-1])

        # Make something that looks like cmd,field1,field2,field3;
        compiled_bytes = self._byte_field_sep.join(fields) + self._byte_command_sep

        # Send the message.
        self.board.write(compiled_bytes)
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

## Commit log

2020-01-29 Updated the location of the lines of text
    Updated the location of the lines of text on the device.
2020-02-17 Size window based on OS
    Added a conditional switch that sizes the main window based on the operating system of the client.
2020-02-24 Removed need for changes to PyCmdMessenger.py
    Removed need for changes to PyCmdMessenger.py, issues with 92nd, 124th and 126th accounts are addressed
    [PassPumpGUI_v2_0_2.py]
2020-04-20 Fixed defect when inserting
    Fixed a defect whereby when inserting the value of the text box the cursor is on before the Insert menu item is selected will become blank.
    [PassPumpGUI_v2_0.py]
2020-04-21 Fixed the group names to reflect any customization
    Read the group names from the ItsyBitsy and display them in the PasswordPumpGUI.
    [PassPumpGUI_v2_0.py]
2020-06-03 Replaced the .ino file with the .py file. Apologies.
    [PassPumpGUI_v2_0.py]
2020-06-14 Create PasswordPump_v_2_0.ino
    Moving PasswordPump_v_2_0.ino into subdirectory PasswordPump_v_2_0 so that it can be more easily opened via the Arduino IDE.
2020-06-30 Added connection from pin 7 to pin 9
    On the picture of the Top PCB, added the connection from pin #7 to pin #9 so that the RGB LED will work correctly with the ItsyBitsy M0.
2020-06-30 Initial create
    Shows the connection between pin 7 and pin 9 for 2.0.4, the version of the PCB that supports the Adafruit ItsyBitsy M0.
2020-07-06 Fixed issues with the style dropdown
    [PassPumpGUI_v2_0.py]
2020-07-19 Fixed an issue w/ GUI when style = 255
    [PassPumpGUI_v2_0.py]
2020-07-22 Added encoder type setting
2020-10-11 Added fix corruption to PasswordPumpGUI
    [PassPumpGUI_v2_0.py]
2020-10-18 Added info about v2.0.5 lefty encoders.
2020-10-18 Fixed a defect in PasswordPumpGUI, various edits to others
    Fixed a defect in PasswordPumpGUI whereby you could navigate to and edit fields before the port was open, resulting in the display of error messages.
    [PassPumpGUI_v2_0.py]
2020-10-26 Added logout timer
2020-10-28 Updated the device burning instructions in the Users Guide
2020-10-30 Adding pictures of the PasswordPump case
2020-11-02 Changes to the Users Guide RE: lefty encoders
2020-11-04 Tightened up Factory Reset
2020-11-04 Fixed a defect related to the RGB LED
2020-11-07 Added the ability to edit More Settings... in the PasswordPumpGUI
    Added the ability to edit RBG LED intensity, login attempts before reset, and minutes of inactivity before logout via the PasswordPumpGUI.
    [PassPumpGUI_v2_0.py]
2020-11-27 Fixed a major defect in export to PasswordPump format
    [PassPumpGUI_v2_0.py]
2020-11-29 Added pics of new case
2020-12-06 Modified the PCB to eliminate pullups for the display.
    Modified the PCB to eliminate the pullups for the I2C SSD1306 display.
    [BoardOutline.gbr, Bottom.gbr, BottomAssy.gbr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]
2020-12-08 Clarified the placment of headers on the ItsyBitsy before soldering
    Clarified the placment of headers on the ItsyBitsy before soldering
2020-12-09 Added a note about the case modifications
2020-12-15 Added instructions for dealing with difficult display soldering
2020-12-16 Updated the users guide for the latest PCB design
2020-12-27 Accomodate a new 3D printed enclosure
    [PwdPumpBoxV2-kl6.stl, PwdPumpLidV2-kl6.stl, passpump-v2-bottom.stl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]
2020-12-27 New case design comment
2021-01-02 Modified the PCB to substitute a joystick for the rotary encoder.
    [BoardOutline.gbr, Bottom.gbr, BottomAssy.gbr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]
2021-01-03 Fixed small issue w/ getRecord
    [PassPumpGUI_v2_0.py]
2021-01-06 Added code to check for updates to PasswordPumpGUI.
    It doesn't automatically download the code, but you can check for updates via Settings-->Check for Updates.
    [PassPumpGUI_v2_0.py]
2021-01-10 Changes to support updating firmware and PasswordPumpGUI program from PasswordPumpGUI
    [PwdPumpBoxV2-6p1.scad]
2021-01-10 Many changes. Details in description.
    Create version 2.0.8 of PasswordPump firmware and PasswordPumpGUI. Updated hardware files for PCB manufacture. Introduced the ability to download the latest version of the firmware and the PasswordPu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
    [Bottom.gbr, BottomMask.gbr, Top.gbr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]
2021-01-15 Joystick related changes
    [BoardOutline.gbr, Bottom.gbr, BottomAssy.gbr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]
2021-01-15 Removed print from updateDirections
2021-01-16 Added info re: case and enclosure
2021-01-31 Adding the 3D .stl and design files
    [EncoderPwdPumpBoxV2-6p1.scad, EncoderPwdPumpBoxV2-kl6.stl, EncoderPwdPumpLidV2-kl6.stl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]
2021-01-31 Edit to comments and copyright notice date, as well as default encoder type
2021-02-04 Added info about the new RaspberryPi executable PasswordPumpGUI file.
2021-02-17 Posting new joystick .stl files and reorganizing 3D print area
    [EncoderPwdPumpBoxV2-6p1.scad, EncoderPwdPumpBoxV2-kl6.stl, EncoderPwdPumpLidV2-kl6.stl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]
2021-02-21 Fixing an issue with joystick orientation when display orientation is changed.
    [PassPumpGUI_v2_0.py]
2021-03-22 New case design
    [PassPumpCase.stl]
2023-03-21 Prevent screen burn in
    Add a feature whereby if Timeout Minutes is set to Never, then the screen will go blank after 5 minutes of inactivity. This is to prevent screen burn in.
    [PasswordPumpRotary.brd]
2024-03-10 Updated the screen saver functionality to stay on the current menu item
    Updated the screen saver functionality to stay on the current menu item
2024-03-24 Different behavior returning from screen timeout
    Changing the way the device behaves when it's returning from screen timeout.
2024-09-02 Updates including fix for 32 char password
    Updates including fix for 32 char password
    [PassPumpGUI_v2_0.py]
